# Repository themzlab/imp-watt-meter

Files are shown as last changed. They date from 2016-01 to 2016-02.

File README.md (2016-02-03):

### imp-watt-meter
single-phase energy meter for AC power.  Uses electric imp

The core of this design is the energy metering ic, ADE7953.  This ic does all of the measuring duties.

An electric imp module imp002 is connected with SPI to read the various metrics such as average active power, V*A, instantaneous current and so on.

The electric imp device reads data from the ADE7953 and packages a binary message.
The electric imp agent recieves this data and unpacks it creating a JSON message and http posts this
to a webhost account

A PHP script recieves this message and logs to a file.

Using the electric imp agent, it is possible to redirect the data to one of many
data repository services.

There is a web page using javascript, jquery and highcharts that will allow one to look at current data and also take a snapshot of the current and voltage waveform or else take a 5 second time plot of the power.

**Additional documentation here**

[visit this project on tumblr](http://themzlab.tumblr.com/wattmeter)

Here is a screenshot of the web page

imp-watt-meter-screenshot-refrigerator

Here is one of the build options.  The case is a PM2425 from polycase.
imp-watt-meter-opened-case

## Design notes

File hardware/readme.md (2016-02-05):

Hardware files are Cadsoft Eagle 7.4

for pcb files
oshpark.com

for stencils
ohararp.com

The BOM file has (hopefully) everything ordered from Digikey for the board assembly.

It does not include the wire to board connectors (faston) nor the case, cordgrips
and other mechanical hardware.

An Image of the top of the board

imp-watt-meter-5 1-bottom

An Image of the bottom of the board.

imp-watt-meter-5 1-top

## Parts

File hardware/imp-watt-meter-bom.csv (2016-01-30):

Digi-Key Part Number | Manufacturer | Manufacturer Part Number | Customer Reference | Quantity 1 | Quantity 2 | Quantity 3 | Mfg Std Lead Time | Description | Comments | RoHS Status | Lead Free Status | REACH Status
945-1400-5-ND | RECOM POWER INC | RAC01-3.3SC | RAC0X | 1 | 0 | 0 | 8 Weeks | CONV AC/DC 1W 3.3V OUT SGL T/H |  | RoHS Compliant | Lead free | Unaffected Jun-2015
P7208-ND | PANASONIC ELECTRONIC COMPONENTS | ERZ-V10D271 | R5 | 1 | 0 | 0 | 15 Weeks | VARISTOR 247V 3.5KA DISC 10MM |  | RoHS Compliant | Lead free | Unaffected Dec-2014
ADE7953ACPZ-ND | ANALOG DEVICES INC | ADE7953ACPZ |  | 1 | 0 | 0 | 9 Weeks | IC ENERGY METERING 1PH 28LFCSP | Alternate Packaging Exists | RoHS Compliant | Lead free | Not Available
Q282-ND | QUALTEK | 739W-X2/20 | 20A VERSION | 1 | 0 | 0 | 17 Weeks | OUTLET PWR NEMA 5-20R SNAPIN/IDC |  | RoHS Compliant | Lead free | Unaffected Jun-2011
445-1592-1-ND | TDK CORPORATION (VA) | C3216X7R1E105K085AA | C12 | 1 | 0 | 0 | 10 Weeks | CAP CER 1UF 25V X7R 1206 | Alternate Packaging Exists | RoHS Compliant | Lead free | Unaffected Jun-2015
709-1074-1-ND | JOHANSON DIELECTRICS INC (VA) | 6R3R18X106KV4E | C15 | 1 | 0 | 0 | 8 Weeks | CAP CER 10UF 6.3V X5R 1206 | Alternate Packaging Exists | RoHS Compliant | Lead free | Unaffected Jun-2015
RMCF0805FT301RCT-ND | STACKPOLE ELECTRONICS INC (VA) | RMCF0805FT301R | RI1 RI2 | 2 | 0 | 0 | 10 Weeks | RES SMD 301 OHM 1% 1/8W 0805 | Alternate Packaging Exists | RoHS Compliant | Lead free | Unaffected Jun-2015
311-1.54KCRCT-ND | YAGEO (VA) | RC0805FR-071K54L | R1 R2 | 2 | 0 | 0 | 22 Weeks | RES SMD 1.54K OHM 1% 1/8W 0805 | Alternate Packaging Exists | RoHS Compliant | Lead free | Unaffected Jun-2015
RMCF0805FT820RCT-ND | STACKPOLE ELECTRONICS INC (VA) | RMCF0805FT820R | R6B R6C | 2 | 0 | 0 | 10 Weeks | RES SMD 820 OHM 1% 1/8W 0805 | Alternate Packaging Exists | RoHS Compliant | Lead free | Unaffected Jun-2015
P15097CT-ND | PANASONIC ELECTRONIC COMPONENTS (VA) | EEE-FTJ681XAP | C4 C8 | 2 | 0 | 0 | 20 Weeks | CAP ALUM 680UF 20% 6.3V SMD | Alternate Packaging Exists | RoHS Compliant | Lead free | Unaffected Dec-2014
RMCF0805JT150RCT-ND | STACKPOLE ELECTRONICS INC (VA) | RMCF0805JT150R | R4 R6 CURRENT LIMIT RESISTOR | 2 | 0 | 0 | 10 Weeks | RES SMD 150 OHM 5% 1/8W 0805 | Alternate Packaging Exists | RoHS Compliant | Lead free | Unaffected Jun-2015
478-2388-1-ND | AVX CORPORATION (VA) | TPSA106K006R1500 | C82;POLARIZED | 1 | 0 | 0 | 12 Weeks | CAP TANT 10UF 6.3V 10% 1206 | Alternate Packaging Exists | RoHS Compliant | Lead free | Unaffected Dec-2015
160-1409-1-ND | LITE-ON INC (VA) | LTST-C155KGJRKT | U1 BICOLOR LED | 1 | 0 | 0 | 10 Weeks | LED GREEN/RED CLEAR 1210 SMD | Alternate Packaging Exists | RoHS Compliant | Lead free | Not Available
1413-1001-1-ND | ELECTRIC IMP INC (VA) | IMP002-S-US-TR | IMP | 1 | 0 | 0 | 8 Weeks | IMP 802.11B/G/N NODE MODULE | Alternate Packaging Exists | RoHS Compliant | Lead free | Unaffected Dec-2013
399-5623-1-ND | KEMET (VA) | C0805C683K5RACTU | C3 C6 68NF C0805K | 2 | 0 | 0 | 8 Weeks | CAP CER 0.068UF 50V X7R 0805 | Alternate Packaging Exists | RoHS Compliant | Lead free | Unaffected Jun-2015
RHM220KBGCT-ND | ROHM SEMICONDUCTOR (PASSIVE) (VA) | MCR50JZHJ224 | R7 R25 | 2 | 0 | 0 | 8 Weeks | RES SMD 220K OHM 5% 1/2W 2010 | Alternate Packaging Exists | RoHS Compliant | Lead free | Unaffected Jun-2015
399-3697-1-ND | KEMET (VA) | T491A475K016AT | C9 C16 C18 | 3 | 0 | 0 | 3 Weeks | CAP TANT 4.7UF 16V 10% 1206 | Alternate Packaging Exists | RoHS Compliant | Lead free | Unaffected Jun-2015
RMCF0805JT100KCT-ND | STACKPOLE ELECTRONICS INC (VA) | RMCF0805JT100K | R8 R9 R10 BLINK-UP RESISTORS | 3 | 0 | 0 | 10 Weeks | RES SMD 100K OHM 5% 1/8W 0805 | Alternate Packaging Exists | RoHS Compliant | Lead free | Unaffected Jun-2015
1080-1384-1-ND | EVERLIGHT ELECTRONICS CO LTD (VA) | PT19-21C/L41/TR8 | PHOTOTRANSISTOR | 1 | 0 | 0 | 8 Weeks | PHOTOTRANSIST FLAT CLR MINI SMD | Alternate Packaging Exists | RoHS Compliant | Lead free | Unaffected Dec-2014
RG20P499BCT-ND | SUSUMU (VA) | RG2012P-4990-B-T5 | R18 R19 | 2 | 0 | 0 | 8 Weeks | RES SMD 499 OHM 0.1% 1/8W 0805 | Alternate Packaging Exists | RoHS Compliant | Lead free | Unaffected Dec-2014
399-1117-1-ND | KEMET (VA) | C0805C470J5GACTU | C14 C48 | 2 | 0 | 0 | 9 Weeks | CAP CER 47PF 50V NP0 0805 | Alternate Packaging Exists | RoHS Compliant | Lead free | Unaffected Jun-2015
445-2187-1-ND | TDK CORPORATION (VA) | MMZ2012D800BT000 | L4 L6 | 2 | 0 | 0 | 10 Weeks | FERRITE BEAD 80 OHM 0805 | Alternate Packaging Exists | RoHS Compliant | Lead free | Unaffected Jun-2015
887-1040-1-ND | TXC CORPORATION (VA) | 9C-3.579545MAAJ-T | CRYSTAL | 1 | 0 | 0 | 12 Weeks | CRYSTAL 3.579545MHZ 18PF SMD | Alternate Packaging Exists | RoHS Compliant | Lead free | Unaffected Dec-2014
311-120KERCT-ND | YAGEO (VA) | RC1206JR-07120KL | R12 R52 | 2 | 0 | 0 | 22 Weeks | RES SMD 120K OHM 5% 1/4W 1206 | Alternate Packaging Exists | RoHS Compliant | Lead free | Unaffected Jun-2015
399-9155-1-ND | KEMET (VA) | C0805C104K9RACTU | C1 C5 C10 C13 C17 C19 | 6 | 0 | 0 | 14 Weeks | CAP CER 0.1UF 6.3V X7R 0805 | Alternate Packaging Exists | RoHS Compliant | Lead free | Unaffected Jun-2015
478-8025-1-ND | AVX CORPORATION (VA) | ESD55C223K4T2A-22 | C2 C84 C85 C7 .022UF C0805K | 4 | 0 | 0 | 10 Weeks | CAP CER 0.022UF 50V X7R 0805 | Alternate Packaging Exists | RoHS Compliant | Lead free | Unaffected Dec-2015
399-1112-1-ND | KEMET (VA) | C0805C180J5GACTU | C71 C72 | 2 | 0 | 0 | 9 Weeks | CAP CER 18PF 50V NP0 0805 | Alternate Packaging Exists | RoHS Compliant | Lead free | Unaffected Jun-2015
399-5986-ND | KEMET | R46KF210000N0K | C11 | 1 | 0 | 0 | 10 Weeks | CAP FILM 10000PF 10% 560VDC RAD |  | RoHS Compliant | Lead free | Unaffected Jun-2015
587-1775-1-ND | TAIYO YUDEN (VA) | FBMJ4516HS111-T | L1 L2 L5; | 3 | 0 | 0 | 4 Weeks | FERRITE BEAD 110 OHM 1806 | Alternate Packaging Exists | RoHS Compliant | Lead free | Not Available
WSLQ-.001CT-ND | VISHAY DALE (VA) | WSL27261L000FEB | R SHUNT, SUBSTITUE 0.0005 FOR MAX I CAPABILITY | 1 | 0 | 0 | 12 Weeks | RES SMD 0.001 OHM 1% 3W 2726 | Alternate Packaging Exists | RoHS Compliant | Lead free | Unaffected Dec-2011
36-3528-ND | KEYSTONE ELECTRONICS | 3528 | FEMALE FASTON FOR CURRENT IN AND OUT | 2 | 0 | 0 | 4 Weeks | CONN QC RCPT 0.250 PRESS-FIT |  | RoHS Compliant | Lead free | Unaffected Jun-2014
WM18762-ND | MOLEX, LLC | 0190040005 | FASTON TO WIRE - MALE INSULATED | 1 | 0 | 0 | 2 Weeks | CONN QC TAB 14-16AWG 0.250 CRIMP |  | RoHS Compliant | Lead free | Unaffected Jun-2015
A107001-ND | TE CONNECTIVITY AMP | 735187-2 | FASTON FOR VRMS SIGNAL INPUT | 1 | 0 | 0 | 7 Weeks | CONN QC TAB 0.110 SOLDER |  | RoHS Compliant | Lead free | Not Available
A27799CT-ND | TE CONNECTIVITY AMP (VA) | 2-520272-2 | WIRE TO FASTON FOR VRMS SIGNAL | 1 | 0 | 0 | 2 Weeks | CONN QC RCPT 18-22AWG 0.110 | Alternate Packaging Exists | RoHS Compliant | Lead free | Not Available
311-200FRCT-ND | YAGEO (VA) | RC1206FR-07200RL | R3; FOR DUMMY LOAD OF POWER SUPPLY | 1 | 0 | 0 | 22 Weeks | RES SMD 200 OHM 1% 1/4W 1206 | Alternate Packaging Exists | RoHS Compliant | Lead free | Unaffected Jun-2015

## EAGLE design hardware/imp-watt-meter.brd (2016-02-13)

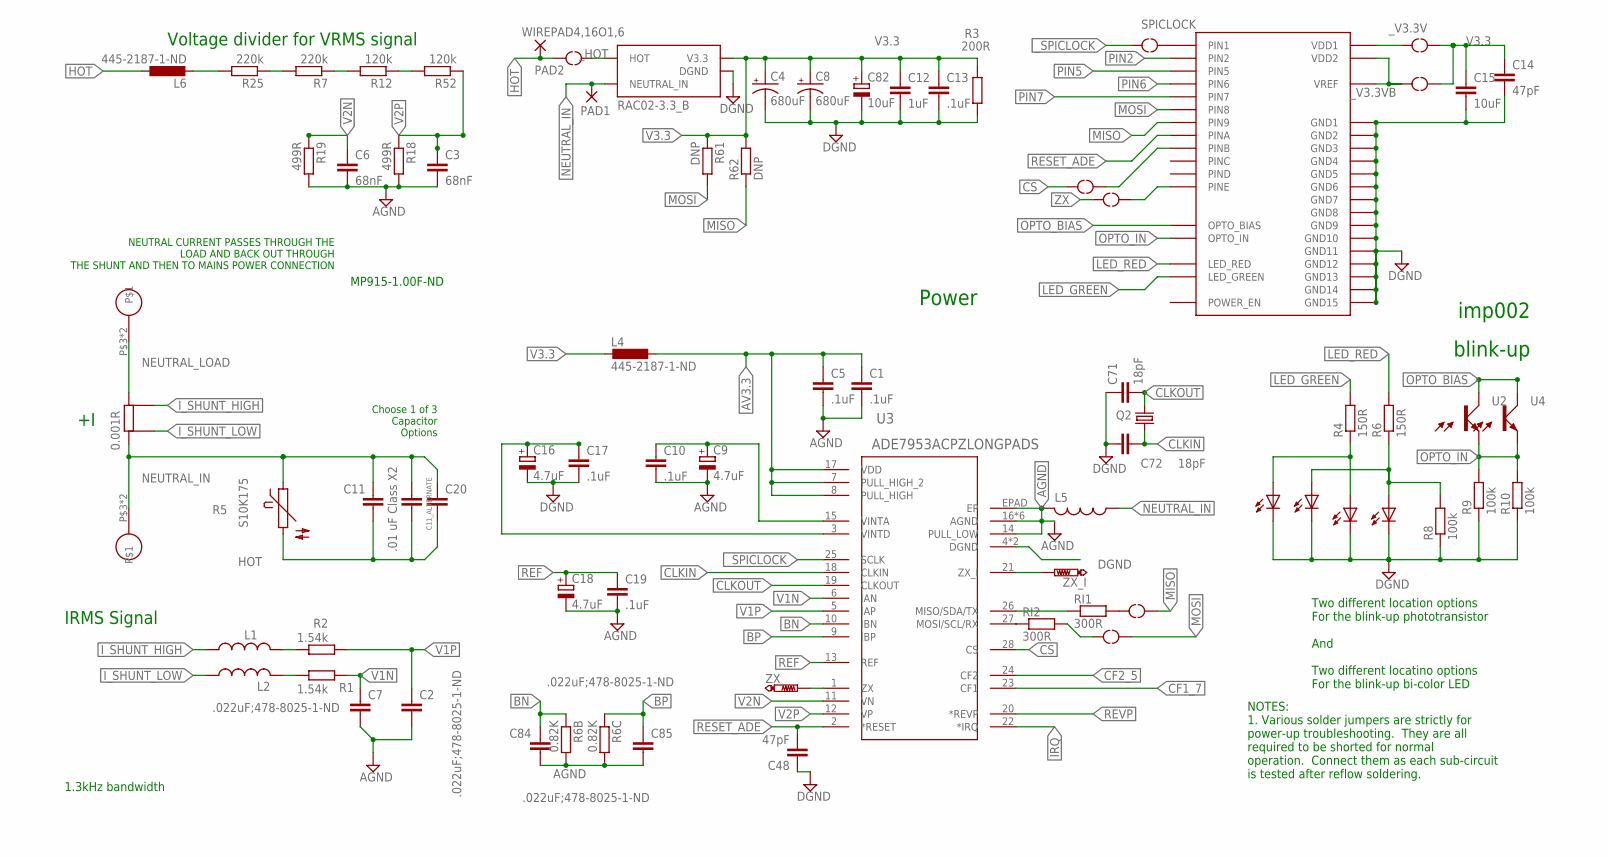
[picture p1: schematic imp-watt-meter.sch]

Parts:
0.001R: WSLP2726L5000FEA; WSLP276_VISHAY
C1, C5, C10, C13, C17, C19: .1uF; C0805K@1
C2, C7, C84, C85: .022uF;478-8025-1-ND; C0805K@1
C3, C6: 68nF; C0805K@1
C4, C8: 680uF; PANASONIC_D
C9, C16, C18: 4.7uF; A/3216-18R
C11, C11_ALTERNATE: .01 uF Class X2; C2220K
C12: 1uF; C1206K
C14, C48: 47pF; C0805K@1
C15: 10uF; 1206
C20: C10/4; C10B4
C71, C72: 18pF; C0805K@1
C82: 10uF; A/3216-18R
L1, L2, L5: L-USL4516C; L4516C
L4, L6: 445-2187-1-ND; L2012C
PAD1, PAD2: WIREPAD4,16O1,6; 4,16O1,6
Q2: 535-10200-1-ND; SM49
R1, R2: 1.54k; C0805K
R3: 200R; M1206
R4, R6: 150R; R0805
R5: S10K175
R6B, R6C: 0.82K; C0805K
R7, R25: 220k; R2010
R8, R9, R10: 100k; R0805
R12, R52: 120k; M1206
R18, R19: 499R; C0805K
R61, R62: DNP; C0805K
RI1, RI2: 300R; R0805@1
U1, U5: LED_DUAL; LED-BICOLOR
U2, U4: PHOTOTRANSISTOR0603; 0603
U3: ADE7953ACPZLONGPADS; VQFN-28-D
U$1: RAC02-3.3_B; RAC02_B
U$2, U$17: KEYSTONE_FASTON; KEYSTONE_FASTON_0.25
U$5: IMP002MANUFACTURING; IMP002
U$10, U$11, U$12, U$13, U$15, U$19: JUMPER2B; SOLDER_JUMPER2B
U$16, U$18: JUMPER3; SOLDER_JUMPER3
ZX: PTR1TP08R; TP08R
ZX_I: PTR1TP08R; TP08R

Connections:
AGND: C1.2, C2.2, C3.2, C5.2, C6.2, C7.2, C9.-, C10.2, C18.-, C19.2, C84.2, C85.2, L5.2, R6B.2, R6C.2, R18.2, R19.2, U3.14 (PULL_LOW), U3.16 (AGND), U3.29 (AGND), U3.30 (AGND), U3.31 (AGND), U3.32 (AGND), U3.EPAD (EP), U3._AGND (AGND)
AV3.3: C1.1, C5.1, L4.1, U3.7 (PULL_HIGH_2), U3.8 (PULL_HIGH), U3.17 (VDD)
BN: C84.1, R6B.1, U3.10 (IBN)
BP: C85.1, R6C.1, U3.9 (IBP)
CALIBRATE_HIGH: L6.2, R25.2
CF1_7: U3.23 (CF1)
CF2_5: U3.24 (CF2)
CLKIN: C72.2, Q2.1, U3.18 (CLKIN)
CLKOUT: C71.2, Q2.2, U3.19 (CLKOUT)
CS: U3.28 (CS), U$10.P$2
DGND: C4.-, C8.-, C12.2, C13.2, C14.2, C15.2, C16.-, C17.2, C48.1, C71.1, C72.1, C82.-, R3.2, R8.1, R9.1, R10.1, U1.3 (C), U1.4 (C), U3.4 (DGND), U3._DGND (DGND), U5.3 (C), U5.4 (C), U$1.P$3 (DGND), U$1.P$5 (DGND), U$1.P$8 (DGND), U$1.P$10 (DGND), U$5.PAD1 (GND1), U$5.PAD7 (GND2), U$5.PAD13 (GND3), U$5.PAD17 (GND4), U$5.PAD23 (GND5), U$5.PAD24 (GND6), U$5.PAD25 (GND7), U$5.PAD26 (GND8), U$5.PAD27 (GND9), U$5.PAD28 (GND10), U$5.PAD29 (GND11), U$5.PAD30 (GND12), U$5.PAD31 (GND13), U$5.PAD32 (GND14), U$5.PAD35 (GND15)
HOT: C11.1, C11_ALTERNATE.1, C20.2, L6.1, PAD2.1, R5.2, U$19.P$1
IRQ: U3.22 (*IRQ)
I_SHUNT_HIGH: 0.001R.P$3, L1.1
I_SHUNT_LOW: 0.001R.P$4, L2.1
LED_GREEN: R4.2, U$5.PAD3 (LED_GREEN)
LED_RED: R6.2, U$5.PAD4 (LED_RED)
MISO: R62.1, U$5.PAD14 (PIN9), U$13.P$1
MOSI: R61.2, U$5.PAD22 (PIN8), U$12.P$1
unnamed: L1.2, R2.2
unnamed: R4.1, U1.1 (A), U5.1 (A)
unnamed: R6.1, R8.2, U1.2 (A), U5.2 (A)
NEUTRAL_IN: 0.001R.P$2 (2), 0.001R.P$8 (2), 0.001R.P$9 (2), 0.001R.P$10 (2), C11.2, C11_ALTERNATE.2, C20.1, L5.1, PAD1.1, R5.1, U$1.P$1 (NEUTRAL_IN), U$1.P$6 (NEUTRAL_IN), U$17.P$3, U$17.P$4
NEUTRAL_LOAD: 0.001R.P$1 (1), 0.001R.P$5 (1), 0.001R.P$6 (1), 0.001R.P$7 (1), U$2.P$3, U$2.P$4
OPTO_BIAS: U2.1 (C), U4.1 (C), U$5.PAD2 (OPTO_BIAS)
OPTO_IN: R9.2, R10.2, U2.2 (E), U4.2 (E), U$5.PAD6 (OPTO_IN)
PIN2: U$5.PAD16 (PIN2)
PIN5: U$5.PAD19 (PIN5)
PIN6: U$5.PAD20 (PIN6)
PIN7: U$5.PAD21 (PIN7)
PIN26_MISO_SDA_TX: RI1.1, U3.26 (MISO/SDA/TX)
PIN27_MOSI_SCL_RX: RI2.1, U3.27 (MOSI/SCL/RX)
REF: C18.+, C19.1, U3.13 (REF)
RESET_ADE: C48.2, U3.2 (*RESET), U$5.PAD8 (PINA)
REVP: U3.20 (*REVP)
SDFSDF: L2.2, R1.2
SPICLOCK: U$5.PAD15 (PIN1), U$11.P$1
V1N: C7.1, R1.1, U3.6 (IAN)
V1P: C2.1, R2.1, U3.5 (IAP)
V2N: C6.1, R19.1, U3.11 (VN)
V2P: C3.1, R18.1, R52.1, U3.12 (VP)
V3.3: C4.+, C8.+, C12.1, C13.1, C14.1, C15.1, C82.+, L4.2, R3.1, R61.1, R62.2, U$1.P$4 (V3.3), U$1.P$9 (V3.3), U$16.P$1, U$18.P$1
VINTA_DCPL: C9.+, C10.1, U3.15 (VINTA)
VINTD_DCPL: C16.+, C17.1, U3.3 (VINTD)
ZX: U3.1 (ZX), U$15.P$2, ZX.TP
ZX_I: U3.21 (ZX_I), ZX_I.TP
_31: R12.1, R52.2
_61: R7.1, R12.2
_118: R7.2, R25.1
_CS: U$5.PAD9 (PINB), U$10.P$1
_HOT: U$1.P$2 (HOT), U$1.P$7 (HOT), U$19.P$2
_I2C_CLOCK_1: RI2.2, U$12.P$2
_I2C_DATA_2: RI1.2, U$13.P$2
_PINE: U$5.PAD12 (PINE), U$15.P$1
_SPICLOCK: U3.25 (SCLK), U$11.P$2
_V3.3V: U$5.PAD18 (VDD1), U$16.P$2
_V3.3VB: U$5.PAD33 (VDD2), U$5.PAD34 (VREF), U$18.P$2

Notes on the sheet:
NEUTRAL CURRENT PASSES THROUGH THE LOAD AND BACK OUT THROUGH THE SHUNT AND THEN TO MAINS POWER CONNECTION
1.3kHz bandwidth
MP915-1.00F-ND
Voltage divider for VRMS signal
blink-up
Power
IRMS Signal
Choose 1 of 3 Capacitor Options
Two different location options For the blink-up phototransistor And Two different locatino options For the blink-up bi-color LED
NOTES: 1. Various solder jumpers are strictly for power-up troubleshooting. They are all required to be shorted for normal operation. Connect them as each sub-circuit is tested after reflow soldering.
imp002

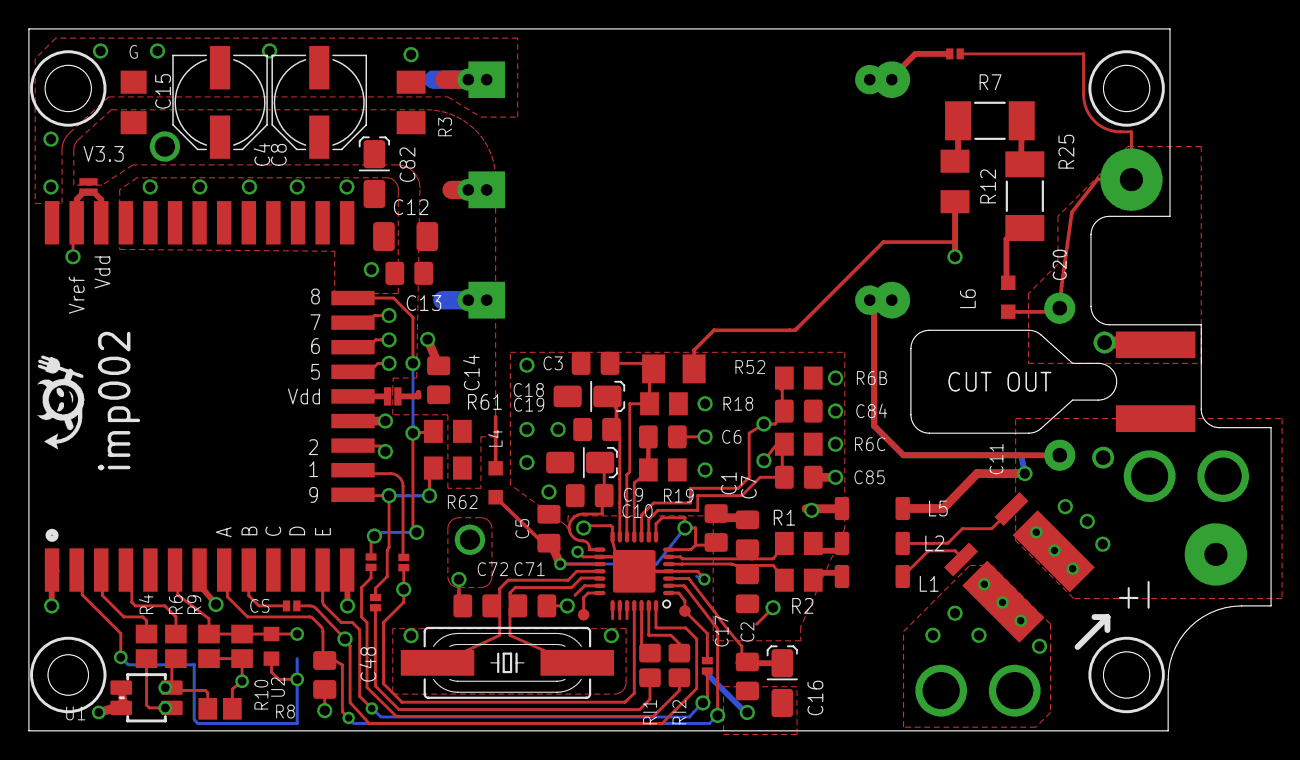
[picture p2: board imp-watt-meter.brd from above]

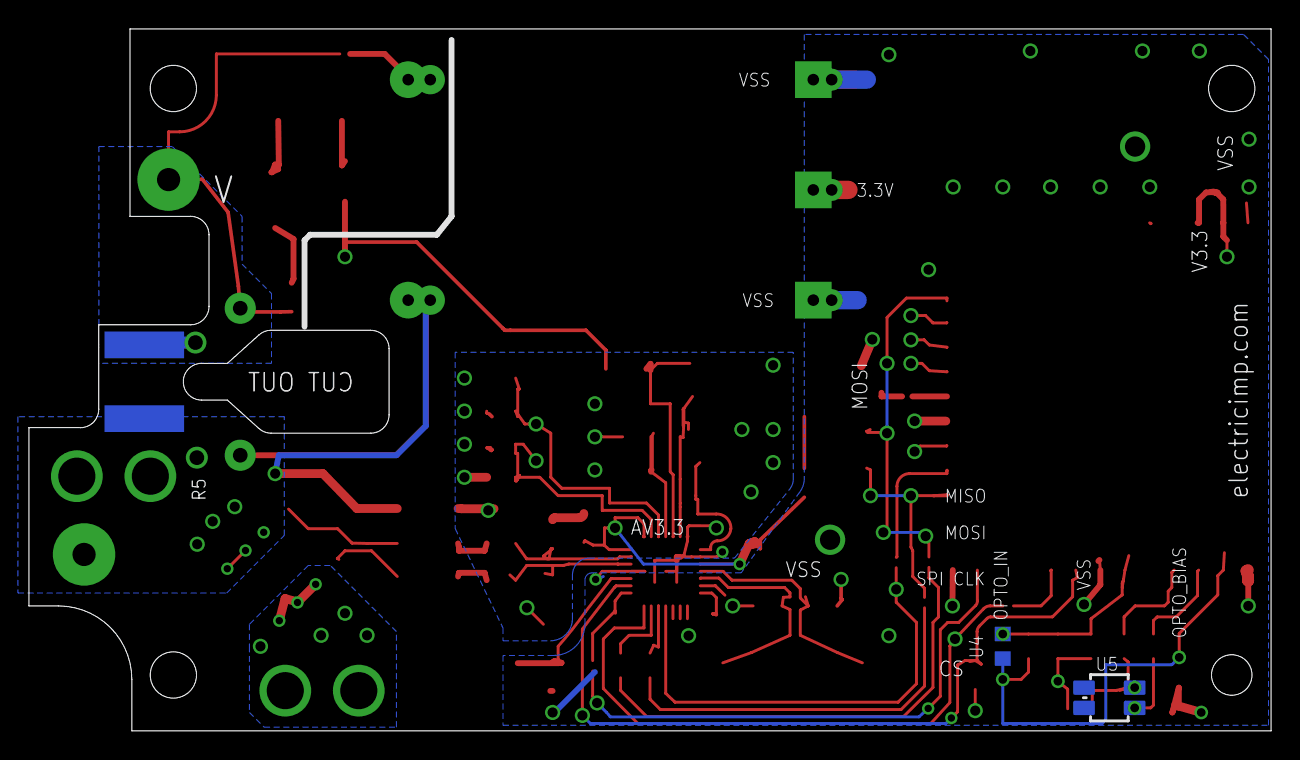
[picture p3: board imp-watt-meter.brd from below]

Board: 2 copper layers, 85.9 x 48.5 mm, 76 parts (3 on the bottom side), 49 nets.

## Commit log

2016-01-30 Create watt-meter-device
2016-02-05 Update watt-meter-device
2016-02-05 updated name of nets to reflect that SPI is used, not i2c
    [imp-watt-meter.brd]
2016-02-05 reflect use of SPI, not i2c in name of nets
    [imp-watt-meter.sch]
2016-02-13 renamed so I could set up default editor using Squirrel's .nut extension
2016-02-13 clarified note on schematic
    [imp-watt-meter.brd, imp-watt-meter.sch]

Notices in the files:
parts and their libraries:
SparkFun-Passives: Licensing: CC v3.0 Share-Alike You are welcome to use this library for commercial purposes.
